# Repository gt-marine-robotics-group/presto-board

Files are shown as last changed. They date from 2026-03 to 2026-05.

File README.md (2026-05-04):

# PRESTO Board

The PRESTO (Peripheral, Radio, and E-Stop) Mainboard project is intended to provide interfaces for standard servo-based peripherals and the emergency stop. Functions that PRESTO provides include direct servo commands, receiving radio control signals, triggering the emergency stop, sensing the emergency stop, and outputing status to a light tower.

## Board Variants

### Presto
Presto is the full functionality variant, designed with as many servo interfaces as possible. This version is intended to serve as an interface for computers with thrusters and peripherals.

### Presto Jr.
Presto Jr. is a reduced functionality variant, with fewer servo interfaces. This version is intended to complement systems with existing frontseat boards controlling thrusters which need to be retrofitted with E-Stop and additional peripherals. 

## Firmware
Firmware can be found [here](https://github.com/gt-marine-robotics-group/firmware-base).

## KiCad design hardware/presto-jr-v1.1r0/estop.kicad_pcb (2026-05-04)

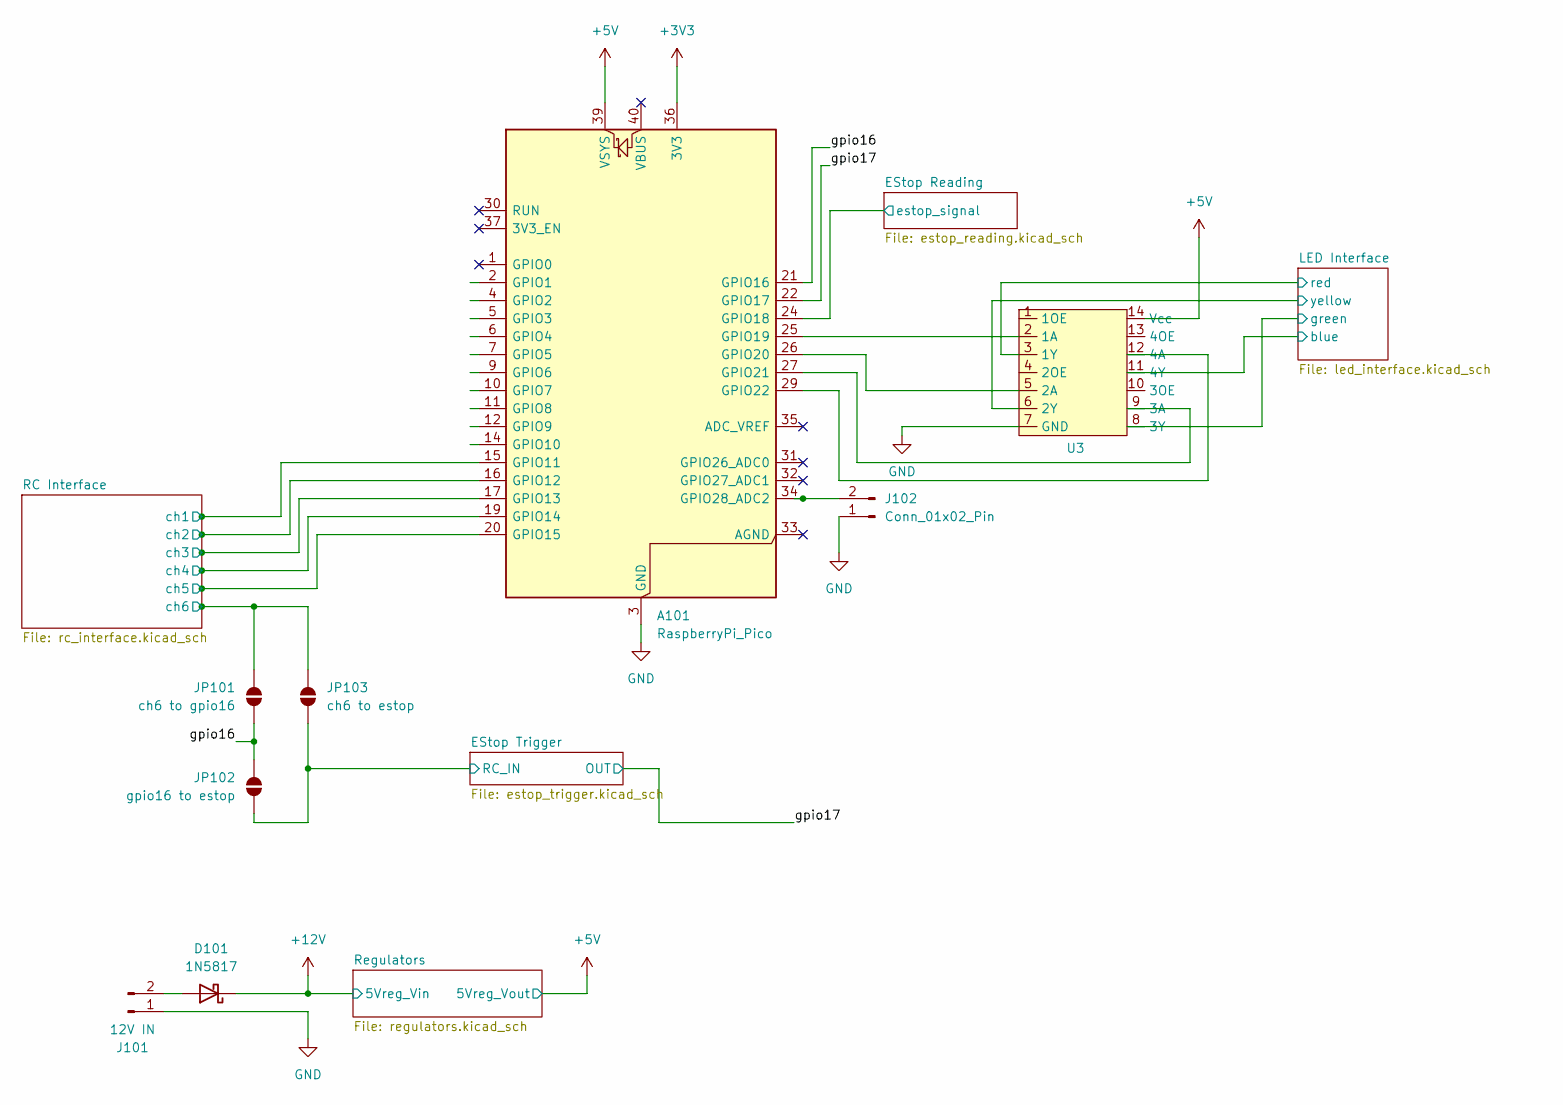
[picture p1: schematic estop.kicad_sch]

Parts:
A101: RaspberryPi_Pico; RaspberryPi_Pico_Common_Unspecified
D101: 1N5817; D_DO-41_SOD81_P10.16mm_Horizontal
J101: 12V IN; AMASS_XT30PW-M_1x02_P2.50mm_Horizontal
J102: Conn_01x02_Pin; JST_XH_B2B-XH-A_1x02_P2.50mm_Vertical
JP101: ch6 to gpio16; SolderJumper-2_P1.3mm_Open_RoundedPad1.0x1.5mm
JP102: gpio16 to estop; SolderJumper-2_P1.3mm_Open_RoundedPad1.0x1.5mm
JP103: ch6 to estop; SolderJumper-2_P1.3mm_Open_RoundedPad1.0x1.5mm
U3: DIP-14_W7.62mm_Socket_LongPads

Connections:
+3V3: A101.36 (3V3); also elsewhere on the board
+5V: A101.39 (VSYS); also elsewhere on the board
+12V: D101.1 (K); also elsewhere on the board
/EStop Reading/estop_signal: A101.24 (GPIO18); also elsewhere on the board
/EStop Trigger/RC_IN: JP102.2 (B), JP103.2 (B); also elsewhere on the board
/LED Interface/blue: U3.11 (4Y); also elsewhere on the board
/LED Interface/green: U3.8 (3Y); also elsewhere on the board
/LED Interface/red: U3.3 (1Y); also elsewhere on the board
/LED Interface/yellow: U3.6 (2Y); also elsewhere on the board
/RC Interface/ch1: A101.15 (GPIO11); also elsewhere on the board
/RC Interface/ch2: A101.16 (GPIO12); also elsewhere on the board
/RC Interface/ch3: A101.17 (GPIO13); also elsewhere on the board
/RC Interface/ch4: A101.19 (GPIO14); also elsewhere on the board
/RC Interface/ch5: A101.20 (GPIO15); also elsewhere on the board
/RC Interface/ch6: JP101.1 (A), JP103.1 (A); also elsewhere on the board
/gpio16: A101.21 (GPIO16), JP101.2 (B), JP102.1 (A)
/gpio17: A101.22 (GPIO17); also elsewhere on the board
GND: A101.3 (GND), A101.8 (GND), A101.13 (GND), A101.18 (GND), A101.23 (GND), A101.28 (GND), A101.38 (GND), J101.1, J102.1, U3.7 (GND); also elsewhere on the board
unnamed: A101.25 (GPIO19), U3.2 (1A)
unnamed: A101.26 (GPIO20), U3.5 (2A)
unnamed: A101.27 (GPIO21), U3.9 (3A)
unnamed: A101.29 (GPIO22), U3.12 (4A)
unnamed: A101.34 (GPIO28_ADC2), J102.2
unnamed: D101.2 (A), J101.2

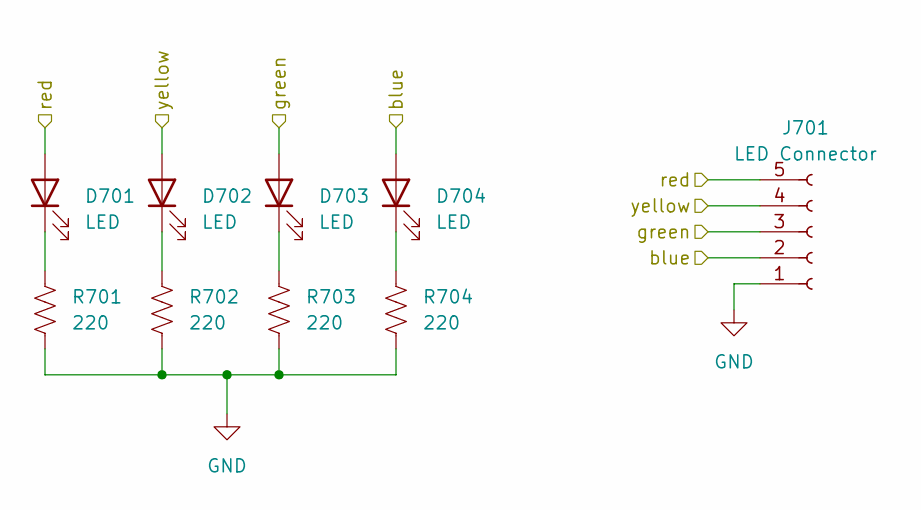
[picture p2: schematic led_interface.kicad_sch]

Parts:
D701, D702, D703, D704: LED; LED_1206_3216Metric_Pad1.42x1.75mm_HandSolder
J701: LED Connector; JST_XH_B5B-XH-A_1x05_P2.50mm_Vertical
R701, R702, R703, R704: 220; R_1206_3216Metric_Pad1.30x1.75mm_HandSolder

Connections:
/LED Interface/blue: D704.2 (A), J701.2; also elsewhere on the board
/LED Interface/green: D703.2 (A), J701.3; also elsewhere on the board
/LED Interface/red: D701.2 (A), J701.5; also elsewhere on the board
/LED Interface/yellow: D702.2 (A), J701.4; also elsewhere on the board
GND: J701.1, R701.2, R702.2, R703.2, R704.2; also elsewhere on the board
unnamed: D701.1 (K), R701.1
unnamed: D702.1 (K), R702.1
unnamed: D703.1 (K), R703.1
unnamed: D704.1 (K), R704.1

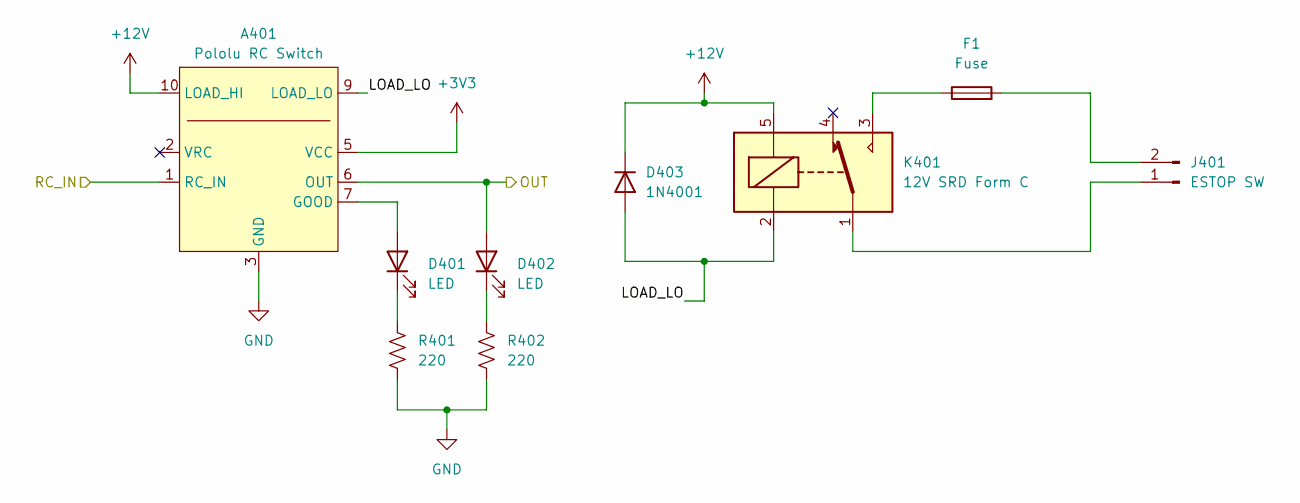
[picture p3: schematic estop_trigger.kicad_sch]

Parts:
A401: Pololu RC Switch; Pololu_2802_RCSw
D401, D402: LED; LED_1206_3216Metric_Pad1.42x1.75mm_HandSolder
D403: 1N4001; D_DO-41_SOD81_P10.16mm_Horizontal
F1: Fuse; Fuseholder_Blade_Mini_Keystone_3568
J401: ESTOP SW; AMASS_XT30PW-M_1x02_P2.50mm_Horizontal
K401: 12V SRD Form C; Relay_SPDT_SANYOU_SRD_Series_Form_C
R401, R402: 220; R_1206_3216Metric_Pad1.30x1.75mm_HandSolder

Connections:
+3V3: A401.5 (VCC); also elsewhere on the board
+12V: A401.10 (LOAD_HI), A401.11 (LOAD_HI), D403.1 (K), K401.5; also elsewhere on the board
/EStop Trigger/LOAD_LO: A401.9 (LOAD_LO), D403.2 (A), K401.2
/EStop Trigger/RC_IN: A401.1 (RC_IN); also elsewhere on the board
/gpio17: A401.6 (OUT), D402.2 (A); also elsewhere on the board
GND: A401.3 (GND), A401.4 (GND), A401.8 (GND), R401.2, R402.2; also elsewhere on the board
unnamed: A401.7 (GOOD), D401.2 (A)
unnamed: D401.1 (K), R401.1
unnamed: D402.1 (K), R402.1
unnamed: F1.1, K401.3
unnamed: J401.1, K401.1
unnamed: F1.2, J401.2

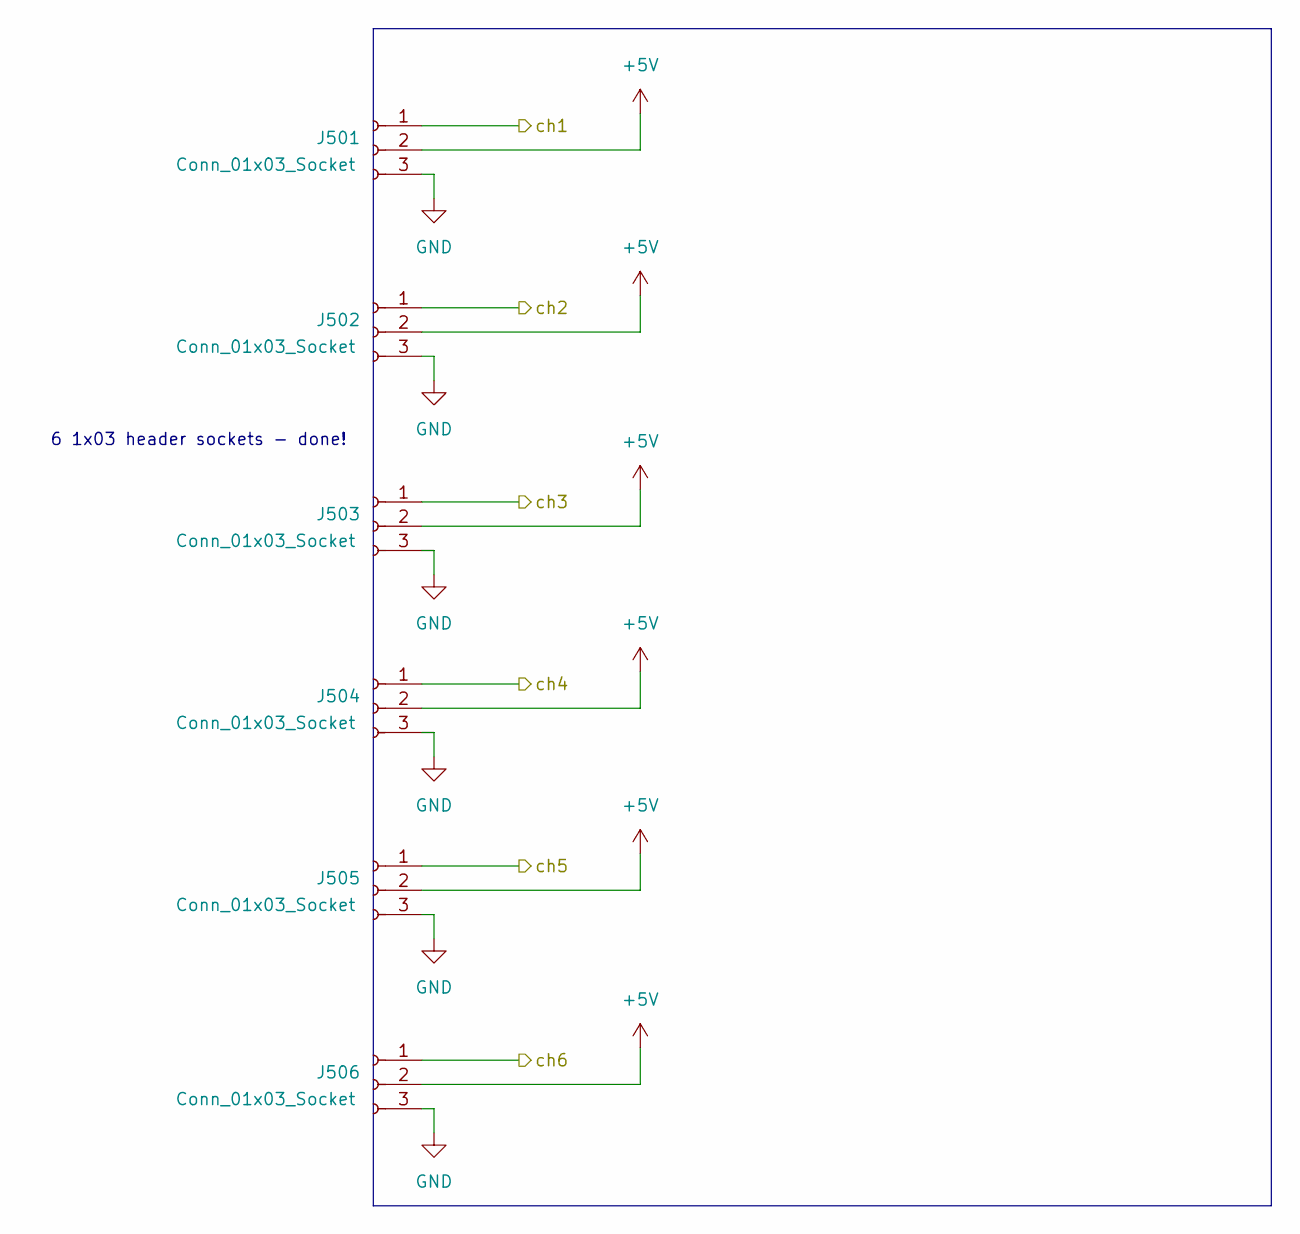
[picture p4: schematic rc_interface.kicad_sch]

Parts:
J501, J502, J503, J504, J505, J506: Conn_01x03_Socket; PinSocket_1x03_P2.54mm_Vertical

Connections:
+5V: J501.2, J502.2, J503.2, J504.2, J505.2, J506.2; also elsewhere on the board
/RC Interface/ch1: J501.1; also elsewhere on the board
/RC Interface/ch2: J502.1; also elsewhere on the board
/RC Interface/ch3: J503.1; also elsewhere on the board
/RC Interface/ch4: J504.1; also elsewhere on the board
/RC Interface/ch5: J505.1; also elsewhere on the board
/RC Interface/ch6: J506.1; also elsewhere on the board
GND: J501.3, J502.3, J503.3, J504.3, J505.3, J506.3; also elsewhere on the board

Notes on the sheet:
6 1x03 header sockets - done!

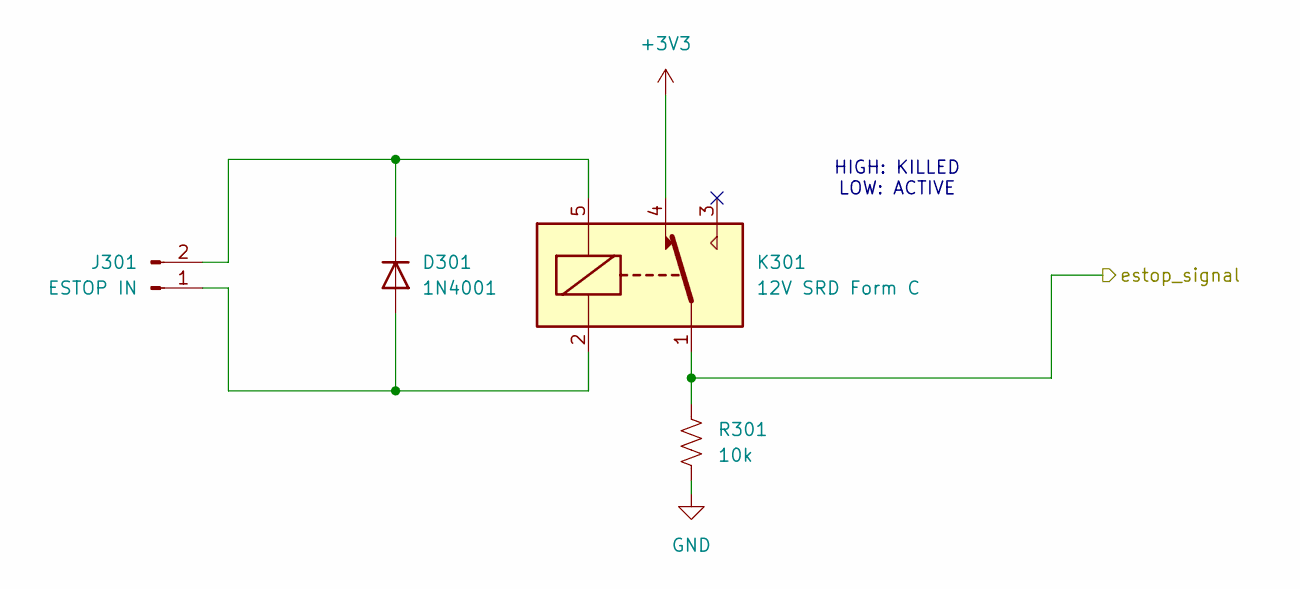
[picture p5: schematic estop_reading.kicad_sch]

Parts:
D301: 1N4001; D_DO-41_SOD81_P10.16mm_Horizontal
J301: ESTOP IN; AMASS_XT30PW-M_1x02_P2.50mm_Horizontal
K301: 12V SRD Form C; Relay_SPDT_SANYOU_SRD_Series_Form_C
R301: 10k; R_Axial_DIN0207_L6.3mm_D2.5mm_P10.16mm_Horizontal

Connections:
+3V3: K301.4; also elsewhere on the board
/EStop Reading/estop_signal: K301.1, R301.1; also elsewhere on the board
GND: R301.2; also elsewhere on the board
unnamed: D301.2 (A), J301.1, K301.2
unnamed: D301.1 (K), J301.2, K301.5

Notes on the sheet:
HIGH: KILLED LOW: ACTIVE

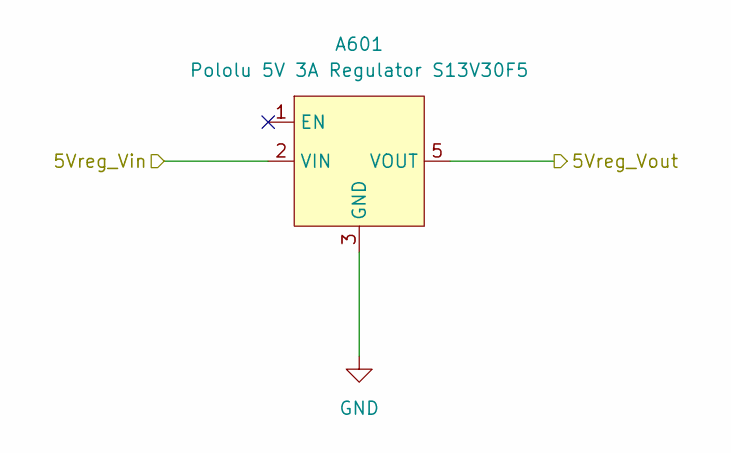
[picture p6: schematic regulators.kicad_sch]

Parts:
A601: Pololu 5V 3A Regulator S13V30F5; Pololu_S13V30F5

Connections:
+5V: A601.5 (VOUT); also elsewhere on the board
+12V: A601.2 (VIN); also elsewhere on the board
GND: A601.3 (GND), A601.4 (GND); also elsewhere on the board

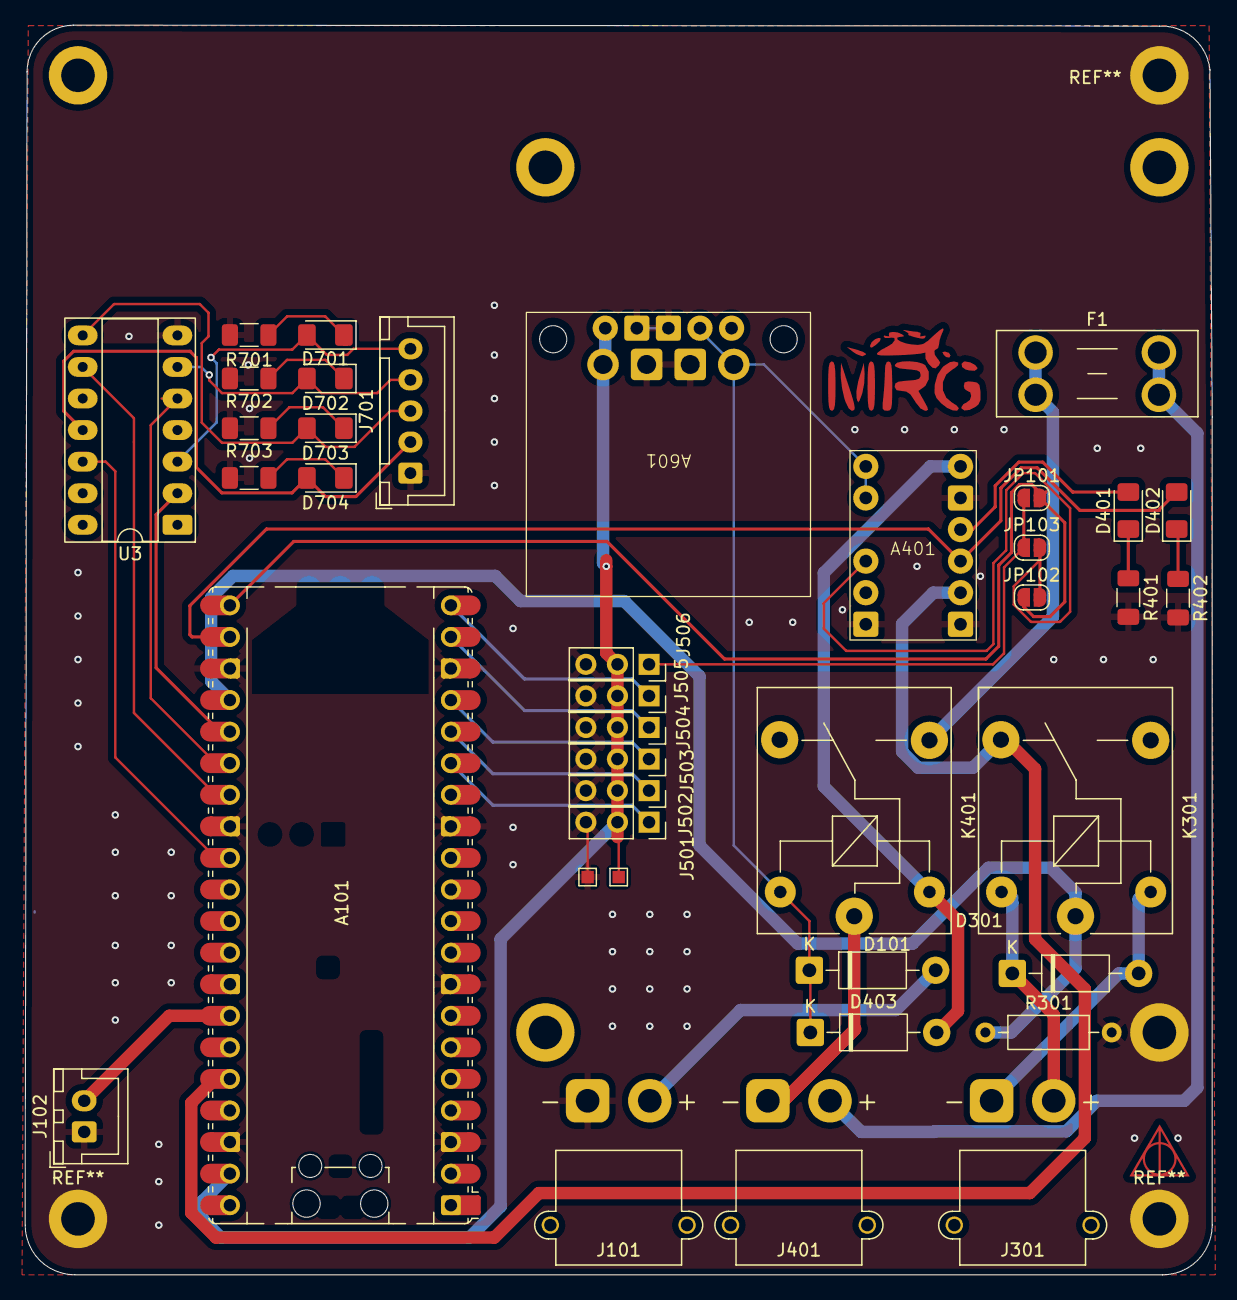
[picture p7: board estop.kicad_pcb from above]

Board: 2 copper layers, 95.5 x 100.5 mm, 37 parts (0 on the bottom side), 37 nets.

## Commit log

2025-09-25 Added kicad project
    [estop_reading.kicad_sch, estop_trigger.kicad_sch, presto.kicad_pcb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]
2025-09-25 Minor document changes
    [estop_reading.kicad_sch, estop_trigger.kicad_sch, rc_interface.kicad_sch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]
2025-10-01 RC and Servo interface schematic done
    [presto.kicad_pcb, presto.kicad_sch, rc_interface.kicad_sch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]
2025-10-08 Added estop, power, led schematics
    [estop_reading.kicad_sch, estop_trigger.kicad_sch, led_interface.kicad_sch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]
2025-10-08 Presto PCB edited with schematic, components placed, wiring in progress
    [estop_reading.kicad_sch, estop_trigger.kicad_sch, presto.kicad_pcb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]
2025-10-19 Presto PCB all wired up, please let me know if any changes are necessary
    [presto.kicad_pcb]
2025-10-22 Presto PCB wired up with most changes implemented + filled zone
    [presto.kicad_pcb]
2025-10-22 LED diode traces not connected properly, deleted, needs to be fixed
    [presto.kicad_pcb]
2025-10-23 Rearranged to accomodate JST
    [presto.kicad_pcb, presto.kicad_sch, servo_interface.kicad_sch]
2025-10-27 Fixed double hole
    [presto.kicad_pcb]
2025-11-07 2-pin JST added for autonomous, 6 routes not connected for some reason though
    [presto.kicad_pcb, presto.kicad_sch]
2026-03-06 added connector for neopixel and fixed autonomy switch layout
    [led_interface.kicad_sch, presto.kicad_pcb, presto.kicad_sch]
2026-03-11 added fuse and changed revision number
    [estop_trigger.kicad_sch, presto.kicad_pcb]
2026-05-04 reorganized and brought in presto jr
    [estop.kicad_pcb, estop.kicad_sch, estop_reading.kicad_sch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]
2026-05-06 reshaped and added v2
    [estop_reading.kicad_sch, estop_trigger.kicad_sch, led_interface.kicad_sch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]
2026-05-07 updated v2
    [led_interface.kicad_sch, presto-jr-v2.0.kicad_pcb, presto-jr-v2.0.kicad_sch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]
2026-06-23 added presto jr
    [estop_reading.kicad_sch, estop_trigger.kicad_sch, led_interface.kicad_sch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]
2026-06-23 update libraries to kicad10
2026-09-01 I forget what I did
    [presto-jr-v2.0.kicad_pcb, presto-jr-v2.0.kicad_sch]
